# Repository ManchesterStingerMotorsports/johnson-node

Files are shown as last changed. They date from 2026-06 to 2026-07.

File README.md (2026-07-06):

# Johnson Node

The Johnson Node is a modular CAN node for sensor networks. It is designed as a small configurable board that can sit on a CAN bus, read local sensors or IO, and publish data for the rest of the network to use.

At its simplest, it is an ADC and IO node on CAN. A lot of the ESP32-S3 IO is broken out to a 14-pin multipin connector, so the same base board can be adapted for different sensor, control, and interface jobs without spinning a whole new main node each time.

The board can also interface with add-on hats. This repo currently includes hat hardware for:

- GPS and IMU
- Strain gauge interface

## Name

This project is named the "Johnson node" after Alexander Johnson, who did a dissertation on the preliminary prototype. 

In reality this project has now far exceeded the scope of the original dissertation but the name remains as a legacy artefact and a reminder of the original work it was built upon, and the iterative nature of engineering development.

> If I have seen further it is by standing on the shoulders of giants.  
> — Isaac Newton

## Repository Layout

| Path | Purpose |
| --- | --- |
| `hardware/johnson-node/` | Main Johnson Node KiCad project, schematic, and PCB. |
| `hardware/hats/IMU, GPS/` | GPS and IMU hat KiCad project. |
| `hardware/hats/Strain Gauge Interface/` | Strain gauge interface hat KiCad project. |
| `main/` | Big Scary Code Blob (jokes, i've actually tried my best to make it readable) |
| `sdkconfig` | ESP-IDF configuration for the ESP32-S3 target. |

## Hardware Overview

The base board is built around an ESP32-S3 module and CAN bus interface. Its role is to provide:

- CAN connectivity for distributed sensor networks.
- Local ADC and IO handling.
- A 14-pin multipin connector exposing a broad set of IO.
- Expansion through application-specific hats.
- A reusable base for different sensor-node configurations.

## Development Notes

- `build/` is generated by ESP-IDF and should not be edited by hand.
- `sdkconfig` is committed so target and flash settings are reproducible.
- The top-level CMake file enables `MINIMAL_BUILD`, so new ESP-IDF component dependencies should be added explicitly in `main/CMakeLists.txt`.

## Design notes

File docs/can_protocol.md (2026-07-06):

# Johnson Node CAN Protocol

The Johnson Node uses 11-bit CAN identifiers at 1 Mbit/s. All multi-byte
values are big-endian. Signed values use two's-complement representation.

This is the initial node-local allocation. It should be reconciled with the
vehicle-wide CAN database before multiple Johnson Nodes are deployed.

## ADC

| ID | Name | Payload |
| --- | --- | --- |
| `0x100` | ADC A | A, B, C, D as four unsigned 16-bit raw counts |
| `0x101` | ADC B | E, F, G, H as four unsigned 16-bit raw counts |

Raw ADC values occupy the range 0 to 4095. Voltage is calculated locally as
`raw * 5.0 / 4096`, but raw values are transmitted so the reference voltage
can be calibrated during analysis.

| Input | Device/channel | Base-board connector |
| --- | --- | --- |
| A | ADC A IN1 | J2 |
| B | ADC A IN2 | J4 |
| C | ADC A IN3 | J3 |
| D | ADC A IN4 | J5 |
| E | ADC B IN1 | J6 |
| F | ADC B IN2 | J7 |
| G | ADC B IN3 | J8 |
| H | ADC B IN4 | J9 |

## IMU

Vector frames contain X, Y, and Z as three signed 16-bit values followed by
two reserved bytes.

| ID | Name | Scale |
| --- | --- | --- |
| `0x110` | Acceleration | `0.01 m/s^2` per bit |
| `0x111` | Linear acceleration | `0.01 m/s^2` per bit |
| `0x112` | Gravity | `0.01 m/s^2` per bit |
| `0x113` | Gyroscope | `0.001 rad/s` per bit |
| `0x114` | Magnetometer | `0.1 uT` per bit |
| `0x115` | Euler orientation | Heading `u16`, roll `i16`, pitch `i16`, two reserved bytes; angles are `0.01 degree` per bit |
| `0x116` | Quaternion | W, X, Y, Z as signed Q14 values |
| `0x117` | IMU status | Packed calibration `u8`, temperature `i8`, six reserved bytes |

The calibration byte is packed as system, gyro, accelerometer, and
magnetometer, with two bits per field in that order.

## GPS

| ID | Name | Payload |
| --- | --- | --- |
| `0x120` | Position | Latitude `i32` and longitude `i32`, both in degrees times `1e7` |
| `0x121` | Motion | Altitude `i32` in centimetres, speed `u16` in centimetres per second, course `u16` in centidegrees |
| `0x122` | GPS status | Flags `u8`, satellites `u8`, HDOP times 100 `u16`, PPS count `u16`, two reserved bytes |
| `0x123` | UTC time | Year `u16`, month, day, hour, minute, second, centisecond |

GPS status flag bit 0 indicates a valid fix. Bit 1 indicates that at least one
PPS edge has been received.

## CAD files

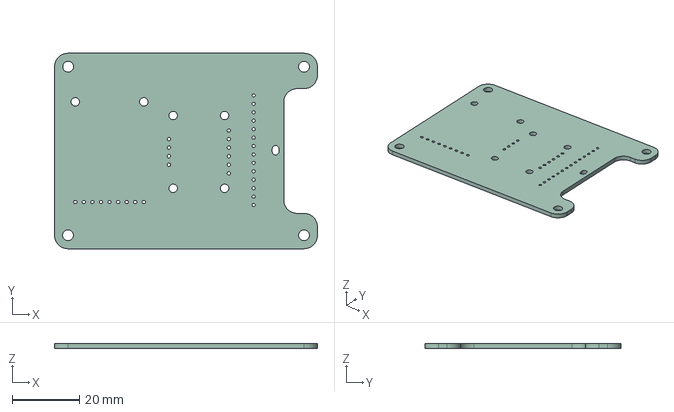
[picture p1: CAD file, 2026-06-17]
hardware/hats/IMU, GPS/.step
78.0 x 58.0 x 1.51 mm

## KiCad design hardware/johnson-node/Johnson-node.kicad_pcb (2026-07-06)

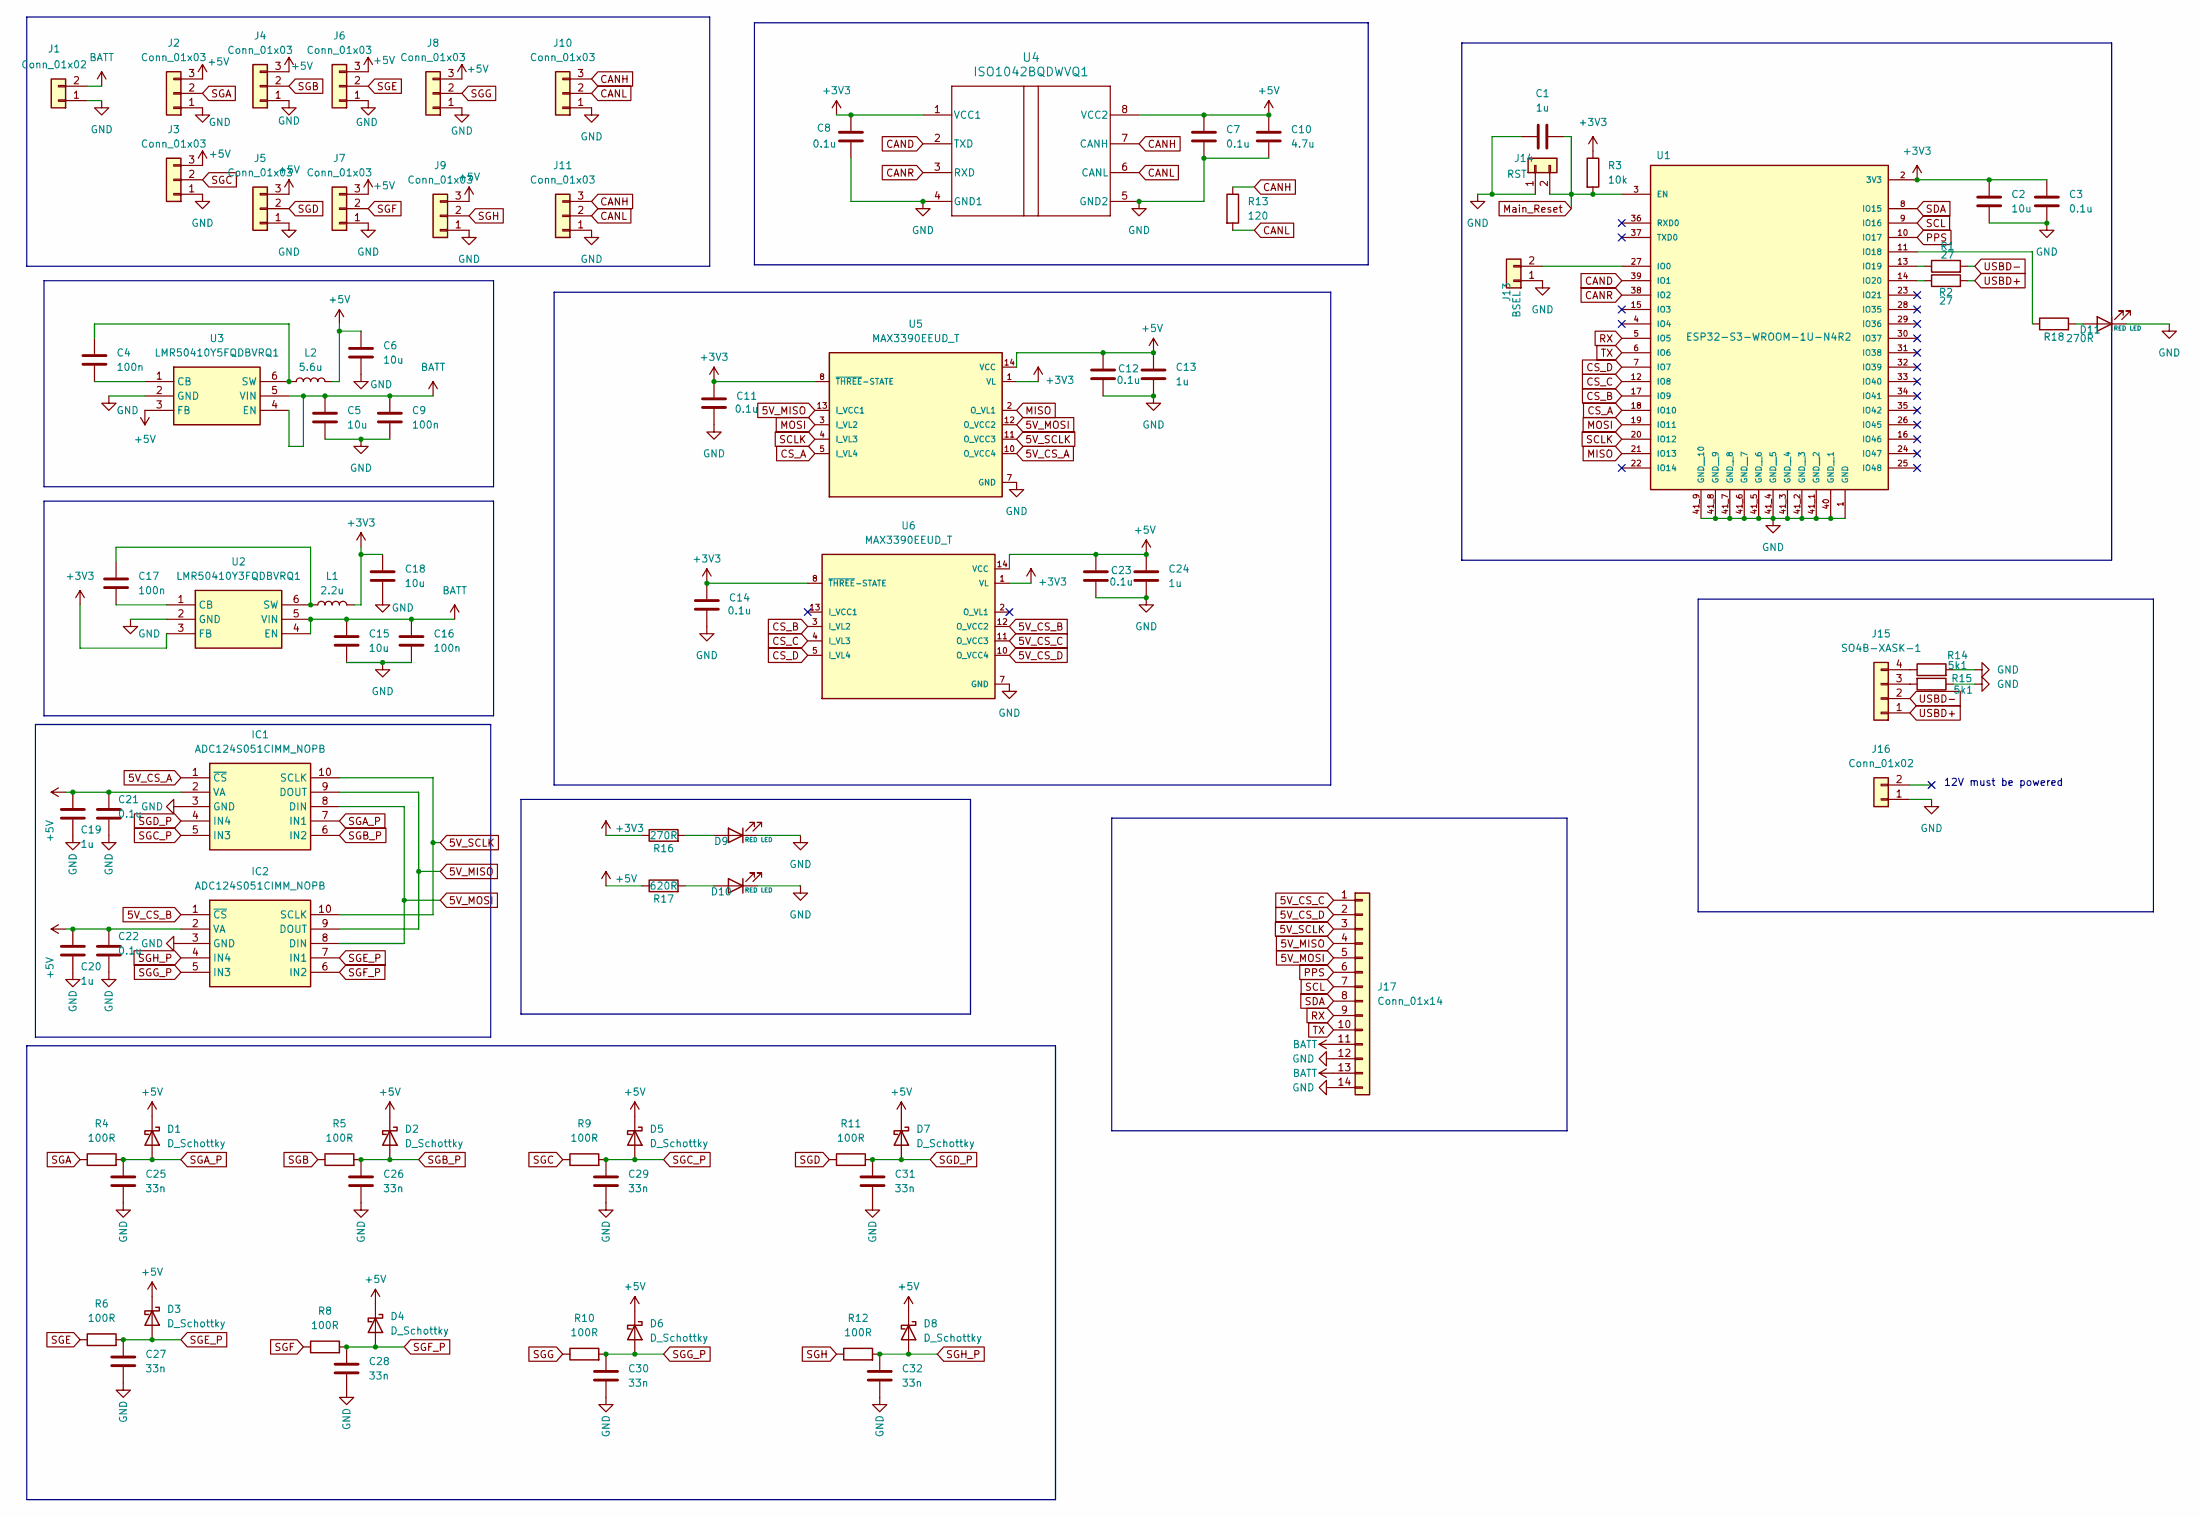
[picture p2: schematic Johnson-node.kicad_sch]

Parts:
C1, C13, C19, C20, C24: 1u; C_0603_1608Metric
C2, C5, C6, C15, C18: 10u; C_0603_1608Metric
C3, C7, C8, C11, C12, C14, C21, C22, C23: 0.1u; C_0603_1608Metric
C4, C9, C16, C17: 100n; C_0603_1608Metric
C10: 4.7u; C_0603_1608Metric
C25, C26, C27, C28, C29, C30, C31, C32: 33n; C_0603_1608Metric
D1, D2, D3, D4, D5, D6, D7, D8: D_Schottky; D_0603_1608Metric
D9, D10, D11: RED LED; LED_0603_1608Metric; Part Number AP2012EC
IC1, IC2: ADC124S051CIMM_NOPB; SOP50P490X110-10N; Mouser Part Number 926-AD124S051CIMMNPB
J1, J16: Conn_01x02; JST_XA_S02B-XASK-1_1x02_P2.50mm_Horizontal
J2, J3, J4, J5, J6, J7, J8, J9, J10, J11: Conn_01x03; JST_XA_S03B-XASK-1_1x03_P2.50mm_Horizontal
J13: BSEL; PinHeader_1x02_P2.54mm_Vertical
J14: RST; PinHeader_1x02_P2.54mm_Vertical
J15: SO4B-XASK-1; JST_XA_S04B-XASK-1_1x04_P2.50mm_Horizontal
J17: Conn_01x14; JST_XA_B14B-XASK-1_1x14_P2.50mm_Vertical
L1: 2.2u; WE-TPC_4828
L2: 5.6u; WE-TPC_4828
R1, R2: 27; R_0603_1608Metric
R3: 10k; R_0603_1608Metric
R4, R5, R6, R8, R9, R10, R11, R12: 100R; R_0603_1608Metric
R13: 120; R_0603_1608Metric
R14, R15: 5k1; R_0603_1608Metric
R16, R18: 270R; R_0603_1608Metric; Part Number RC0805FR-07270RL
R17: 620R; R_0603_1608Metric; Part Number RC0805FR-07270RL
U1: ESP32-S3-WROOM-1U-N4R2; XCVR_ESP32-S3-WROOM-1U-N4R2; PARTREV v1.1
U2: LMR50410Y3FQDBVRQ1; SOT95P280X145-6N; Mouser Part Number 595-R50410Y3FQDBVRQ1
U3: LMR50410Y5FQDBVRQ1; SOT95P280X145-6N; Mouser Part Number 595-R50410Y3FQDBVRQ1
U4: ISO1042BQDWVQ1; DWV0008A-MFG
U5, U6: MAX3390EEUD_T; SOP65P640X110-14N

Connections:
5V_CS_A: IC1.1 (~CS), U5.10 (O_VCC4)
5V_CS_B: IC2.1 (~CS), U6.12 (O_VCC2)
5V_CS_C: J17.1, U6.11 (O_VCC3)
5V_CS_D: J17.2, U6.10 (O_VCC4)
5V_MISO: IC1.9 (DOUT), IC2.9 (DOUT), J17.4, U5.13 (I_VCC1)
5V_MOSI: IC1.8 (DIN), IC2.8 (DIN), J17.5, U5.12 (O_VCC2)
5V_SCLK: IC1.10 (SCLK), IC2.10 (SCLK), J17.3, U5.11 (O_VCC3)
+3V3: C2.2, C3.2, C8.2, C11.1, C14.1, C18.1, L1.2, R3.1, R16.1, U1.2 (3V3), U2.3 (FB), U4.1 (VCC1), U5.1 (VL), U5.8 (~THREE-STATE), U6.1 (VL), U6.8 (~THREE-STATE)
+5V: C6.1, C7.2, C10.2, C12.1, C13.1, C19.1, C20.1, C21.1, C22.1, C23.1, C24.1, D1.1 (K), D2.1 (K), D3.1 (K), D4.1 (K), D5.1 (K), D6.1 (K), D7.1 (K), D8.1 (K), IC1.2 (VA), IC2.2 (VA), J2.3, J3.3, J4.3, J5.3, J6.3, J7.3, J8.3, J9.3, L2.2, R17.1, U3.3 (FB), U4.8 (VCC2), U5.14 (VCC), U6.14 (VCC)
BATT: C5.1, C9.1, C15.1, C16.1, J1.2, J17.11, J17.13, U2.4 (EN), U2.5 (VIN), U3.4 (EN), U3.5 (VIN)
CAND: U1.39 (IO1), U4.2 (TXD)
CANH: J10.3, J11.3, R13.1, U4.7 (CANH)
CANL: J10.2, J11.2, R13.2, U4.6 (CANL)
CANR: U1.38 (IO2), U4.3 (RXD)
CS_A: U1.18 (IO10), U5.5 (I_VL4)
CS_B: U1.17 (IO9), U6.3 (I_VL2)
CS_C: U1.12 (IO8), U6.4 (I_VL3)
CS_D: U1.7 (IO7), U6.5 (I_VL4)
GND: C1.1, C2.1, C3.1, C5.2, C6.2, C7.1, C8.1, C9.2, C10.1, C11.2, C12.2, C13.2, C14.2, C15.2, C16.2, C18.2, C19.2, C20.2, C21.2, C22.2, C23.2, C24.2, C25.2, C26.2, C27.2, C28.2, C29.2, C30.2, C31.2, C32.2, D9.1 (K), D10.1 (K), D11.1 (K), IC1.3 (GND), IC2.3 (GND), J1.1, J2.1, J3.1, J4.1, J5.1, J6.1, J7.1, J8.1, J9.1, J10.1, J11.1, J13.1, J14.1, J16.1 (Pin_1_1), J17.12, J17.14, R14.2, R15.1, U1.1 (GND), U1.40 (GND__1), U1.41_1 (GND__2), U1.41_2 (GND__3), U1.41_3 (GND__4), U1.41_4 (GND__5), U1.41_5 (GND__6), U1.41_6 (GND__7), U1.41_7 (GND__8), U1.41_8 (GND__9), U1.41_9 (GND__10), U2.2 (GND), U3.2 (GND), U4.4 (GND1), U4.5 (GND2), U5.7 (GND), U6.7 (GND); also elsewhere on the board
MISO: U1.21 (IO13), U5.2 (O_VL1)
MOSI: U1.19 (IO11), U5.3 (I_VL2)
Main_Reset: C1.2, J14.2, R3.2, U1.3 (EN)
unnamed 22: D9.2 (A), R16.2; also elsewhere on the board
unnamed 23: D10.2 (A), R17.2; also elsewhere on the board
unnamed 24: D11.2 (A), R18.2; also elsewhere on the board
unnamed: J13.2, U1.27 (IO0)
unnamed: J15.3, R15.2
unnamed: J15.4, R14.1
unnamed: R18.1, U1.11 (IO18)
unnamed: R1.1, U1.13 (IO19)
unnamed: R2.1, U1.14 (IO20)
unnamed: C17.2, U2.1 (CB)
unnamed: C17.1, L1.1, U2.6 (SW)
unnamed: C4.2, U3.1 (CB)
unnamed: C4.1, L2.1, U3.6 (SW)
PPS: J17.6, U1.10 (IO17)
RX: J17.9, U1.5 (IO5)
SCL: J17.7, U1.9 (IO16)
SCLK: U1.20 (IO12), U5.4 (I_VL3)
SDA: J17.8, U1.8 (IO15)
SGA: J2.2, R4.1
SGA_P: C25.1, D1.2 (A), IC1.7 (IN1), R4.2
SGB: J4.2, R5.1
SGB_P: C26.1, D2.2 (A), IC1.6 (IN2), R5.2
SGC: J3.2, R9.1
SGC_P: C29.1, D5.2 (A), IC1.5 (IN3), R9.2
SGD: J5.2, R11.1
SGD_P: C31.1, D7.2 (A), IC1.4 (IN4), R11.2
SGE: J6.2, R6.1
SGE_P: C27.1, D3.2 (A), IC2.7 (IN1), R6.2
SGF: J7.2, R8.1
SGF_P: C28.1, D4.2 (A), IC2.6 (IN2), R8.2
SGG: J8.2, R10.1
SGG_P: C30.1, D6.2 (A), IC2.5 (IN3), R10.2
SGH: J9.2, R12.1
SGH_P: C32.1, D8.2 (A), IC2.4 (IN4), R12.2
TX: J17.10, U1.6 (IO6)
USBD+: J15.1, R2.2
USBD-: J15.2, R1.2

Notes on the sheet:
12V must be powered

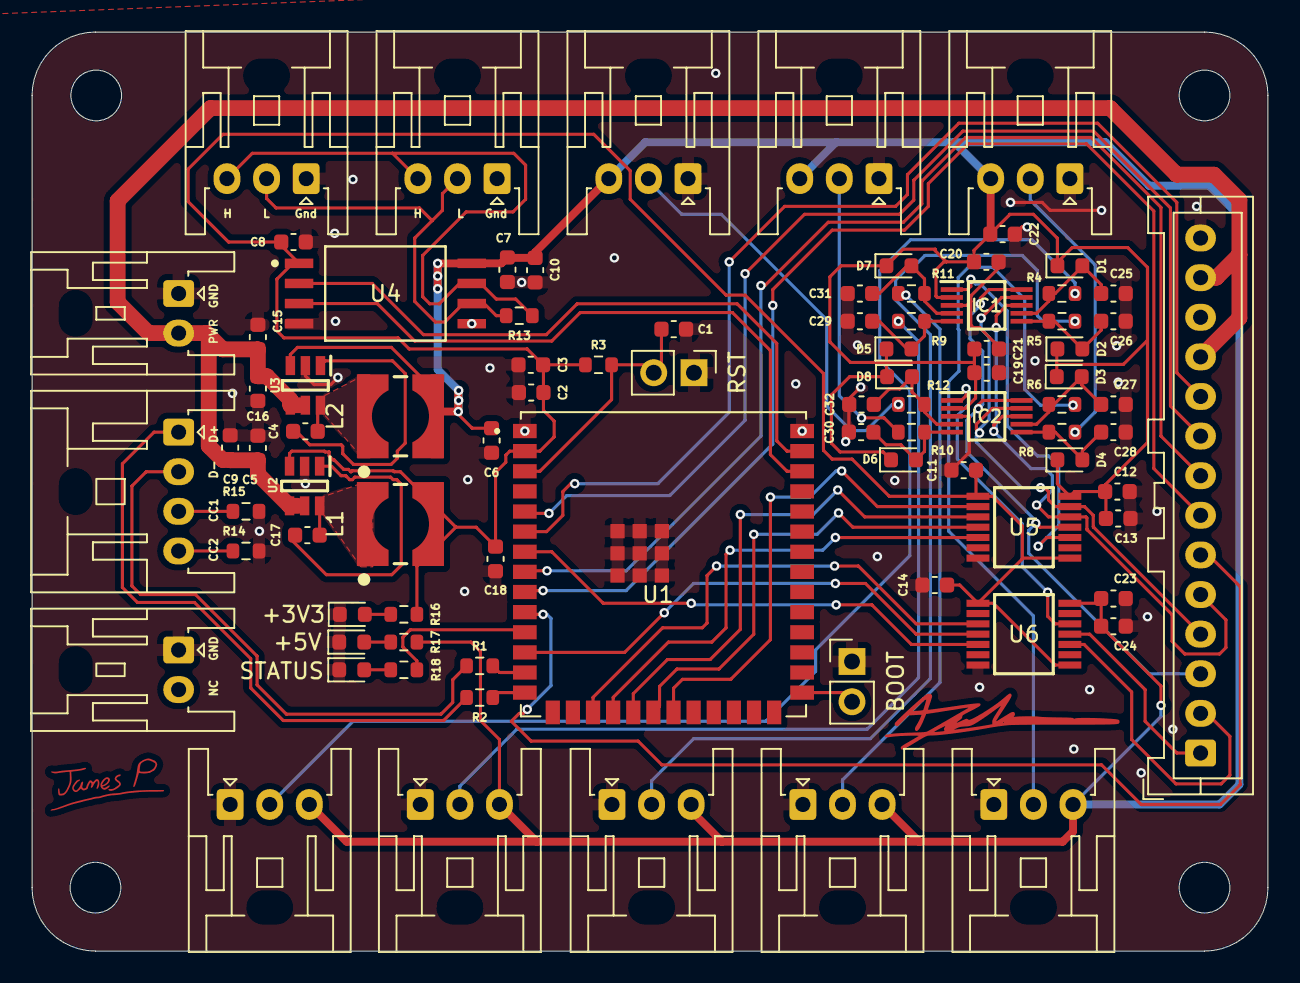
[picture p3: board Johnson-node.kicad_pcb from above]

Board: 2 copper layers, 78.0 x 58.0 mm, 86 parts (0 on the bottom side), 59 nets.

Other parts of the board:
+3V3, +5V: RED LED; LED_0603_1608Metric
STATUS: RED LED; LED_0603_1608Metric

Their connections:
GND: +3V3.1 (K), +5V.1 (K), STATUS.1 (K); also elsewhere on the board
unnamed 22: +3V3.2 (A); also elsewhere on the board
unnamed 23: +5V.2 (A); also elsewhere on the board
unnamed 24: STATUS.2 (A); also elsewhere on the board

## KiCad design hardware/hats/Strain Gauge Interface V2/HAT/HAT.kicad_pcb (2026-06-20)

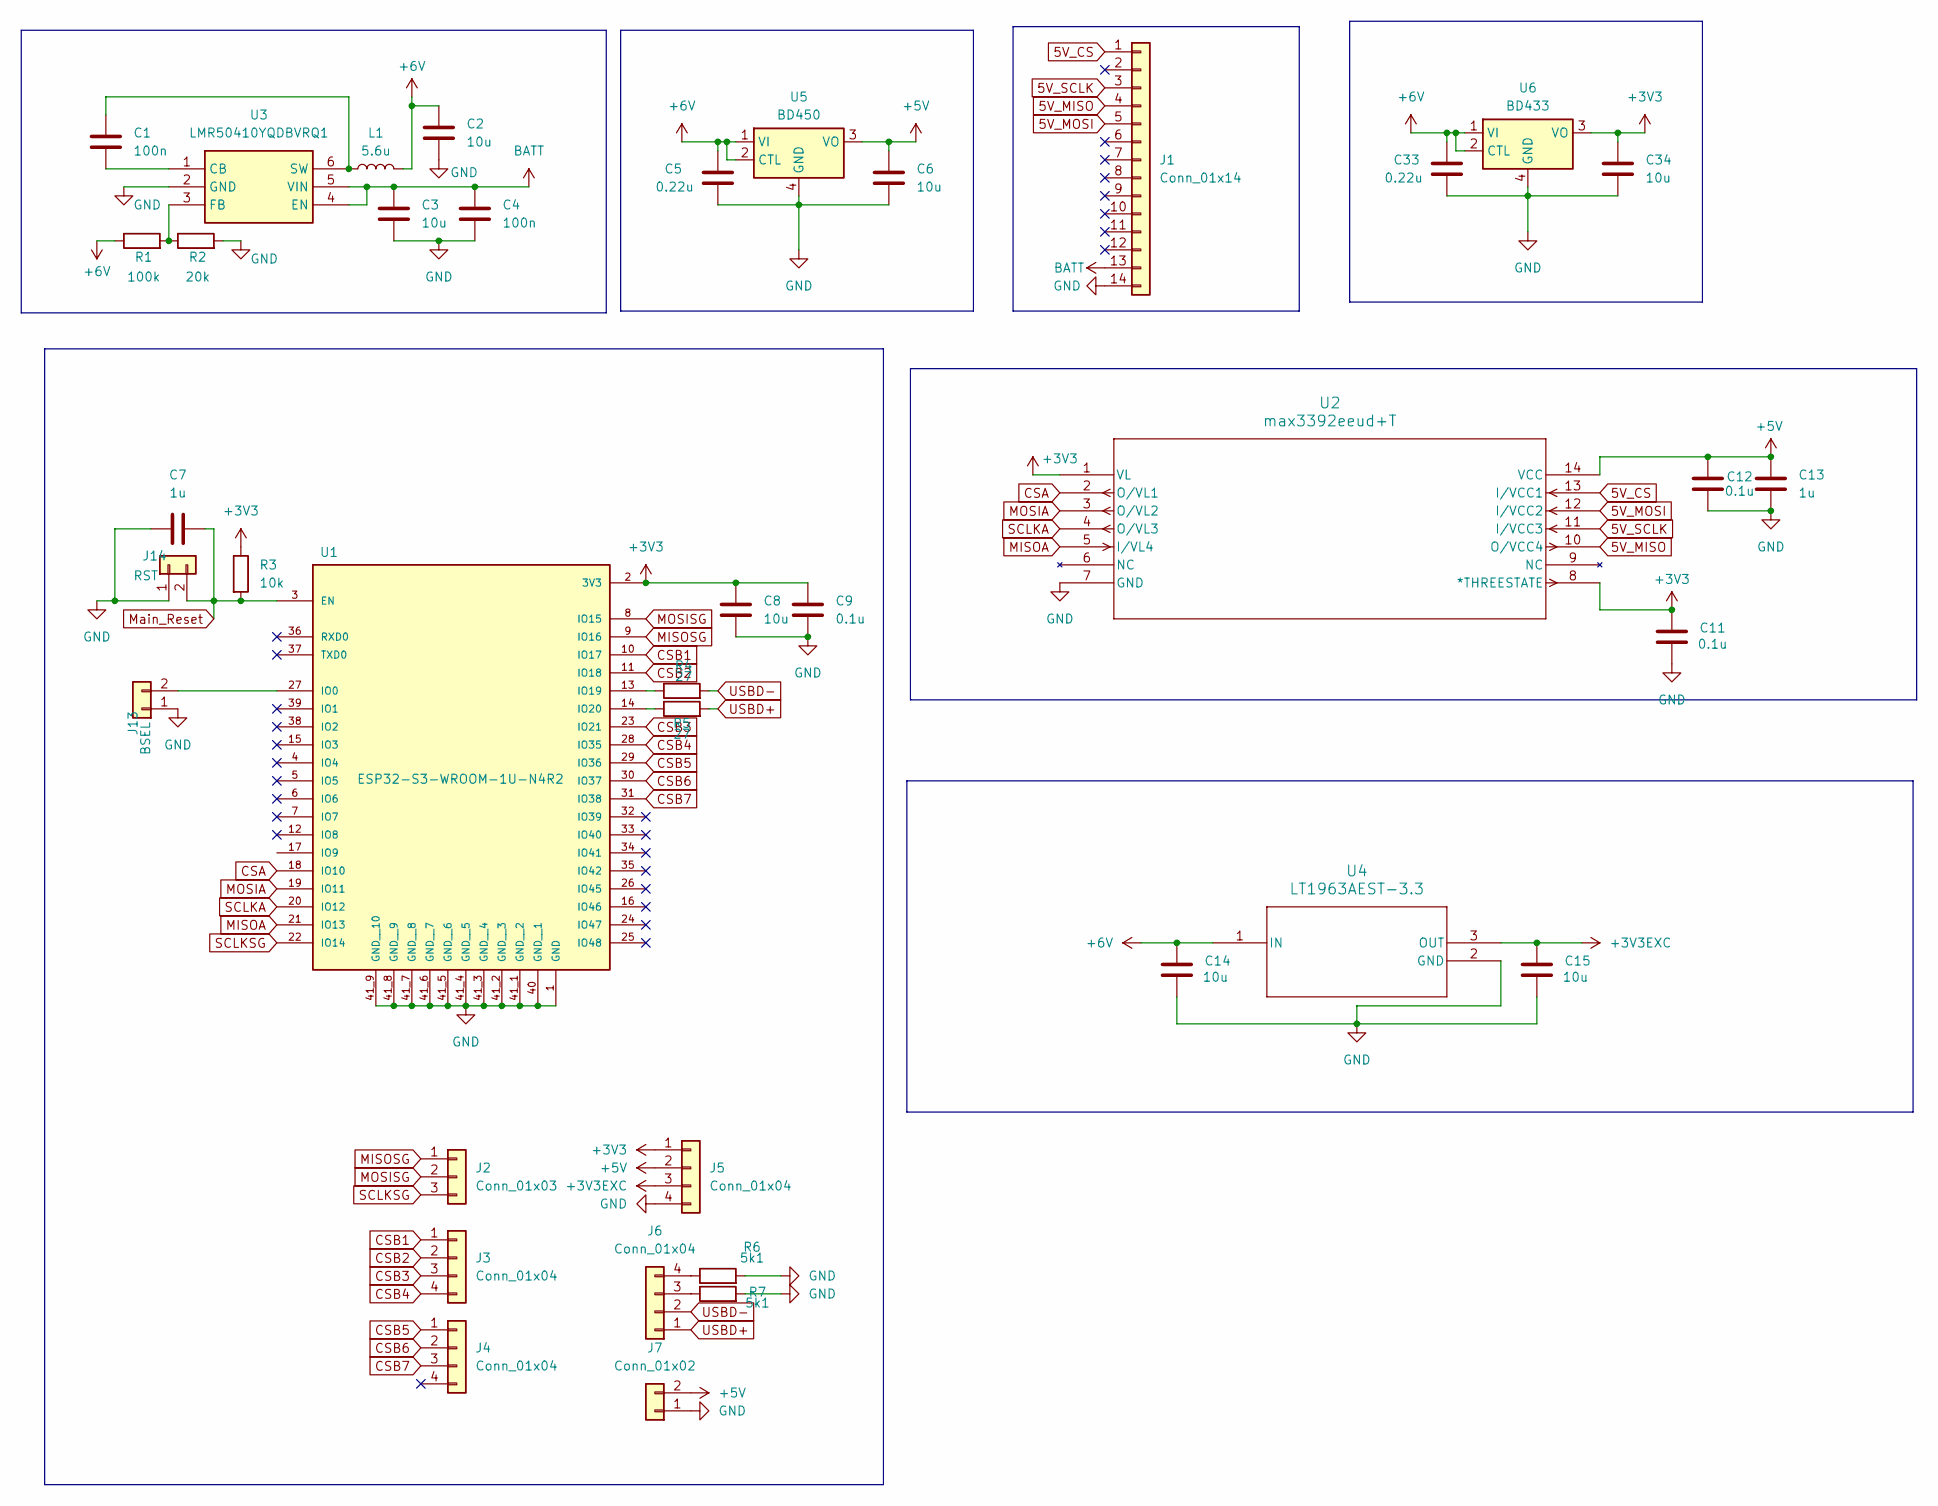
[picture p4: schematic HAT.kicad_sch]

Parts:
C1, C4: 100n; C_0603_1608Metric
C2, C3, C6, C8, C14, C15, C34: 10u; C_0603_1608Metric
C5, C33: 0.22u; C_0603_1608Metric
C7, C13: 1u; C_0603_1608Metric
C9, C11, C12: 0.1u; C_0603_1608Metric
J1: Conn_01x14; JST_XA_S14B-XASK-1_1x14_P2.50mm_Horizontal
J2: Conn_01x03; JST_XA_S03B-XASK-1_1x03_P2.50mm_Horizontal
J3, J4, J5, J6: Conn_01x04; JST_XA_S04B-XASK-1_1x04_P2.50mm_Horizontal
J7: Conn_01x02; JST_XA_S02B-XASK-1_1x02_P2.50mm_Horizontal
J13: BSEL; PinHeader_1x02_P2.54mm_Vertical
J14: RST; PinHeader_1x02_P2.54mm_Vertical
L1: 5.6u; WE-TPC_4828
R1: 100k; R_0603_1608Metric
R2: 20k; R_0603_1608Metric
R3: 10k; R_0603_1608Metric
R4, R5: 27; R_0603_1608Metric
R6, R7: 5k1; R_0603_1608Metric
U1: ESP32-S3-WROOM-1U-N4R2; XCVR_ESP32-S3-WROOM-1U-N16R8; PARTREV v1.1
U2: max3392eeud+T; 21-0066J_14_MXM
U3: LMR50410YQDBVRQ1; Regulator_Switching_SOT-23-6; Mouser Part Number 595-R50410Y3FQDBVRQ1
U4: LT1963AEST-3.3; SOT-223-3_TabPin2
U5: BD450; Regulator_Linear_SOT-223-4
U6: BD433; Regulator_Linear_SOT-223-4

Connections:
5V_CS: J1.1, U2.13 (I/VCC1)
5V_MISO: J1.4, U2.10 (O/VCC4)
5V_MOSI: J1.5, U2.12 (I/VCC2)
5V_SCLK: J1.3, U2.11 (I/VCC3)
+3V3: C8.2, C9.2, C11.1, C34.1, J5.1, R3.1, U1.2 (3V3), U2.1 (VL), U2.8 (*THREESTATE), U6.3 (VO)
+3V3EXC: C15.1, J5.3, U4.3 (OUT)
+5V: C6.1, C12.1, C13.1, J5.2, J7.2, U2.14 (VCC), U5.3 (VO)
+6V: C2.1, C5.1, C14.1, C33.1, L1.2, R1.1, U4.1 (IN), U5.1 (VI), U5.2 (CTL), U6.1 (VI), U6.2 (CTL)
BATT: C3.1, C4.1, J1.13, U3.4 (EN), U3.5 (VIN)
CSA: U1.18 (IO10), U2.2 (O/VL1)
CSB1: J3.1, U1.10 (IO17)
CSB2: J3.2, U1.11 (IO18)
CSB3: J3.3, U1.23 (IO21)
CSB4: J3.4, U1.28 (IO35)
CSB5: J4.1, U1.29 (IO36)
CSB6: J4.2, U1.30 (IO37)
CSB7: J4.3, U1.31 (IO38)
GND: C2.2, C3.2, C4.2, C5.2, C6.2, C7.1, C8.1, C9.1, C11.2, C12.2, C13.2, C14.2, C15.2, C33.2, C34.2, J1.14, J5.4, J7.1, J13.1, J14.1, R2.2, R6.2, R7.2, U1.1 (GND), U1.40 (GND__1), U1.41_1 (GND__2), U1.41_2 (GND__3), U1.41_3 (GND__4), U1.41_4 (GND__5), U1.41_5 (GND__6), U1.41_6 (GND__7), U1.41_7 (GND__8), U1.41_8 (GND__9), U1.41_9 (GND__10), U2.7 (GND), U3.2 (GND), U4.2 (GND), U5.4 (GND), U6.4 (GND)
MISOA: U1.21 (IO13), U2.5 (I/VL4)
MISOSG: J2.1, U1.9 (IO16)
MOSIA: U1.19 (IO11), U2.3 (O/VL2)
MOSISG: J2.2, U1.8 (IO15)
Main_Reset: C7.2, J14.2, R3.2, U1.3 (EN)
unnamed: J6.3, R7.1
unnamed: J6.4, R6.1
unnamed: J13.2, U1.27 (IO0)
unnamed: R4.1, U1.13 (IO19)
unnamed: R5.1, U1.14 (IO20)
unnamed: C1.2, U3.1 (CB)
unnamed: R1.2, R2.1, U3.3 (FB)
unnamed: C1.1, L1.1, U3.6 (SW)
SCLKA: U1.20 (IO12), U2.4 (O/VL3)
SCLKSG: J2.3, U1.22 (IO14)
USBD+: J6.1, R5.2
USBD-: J6.2, R4.2

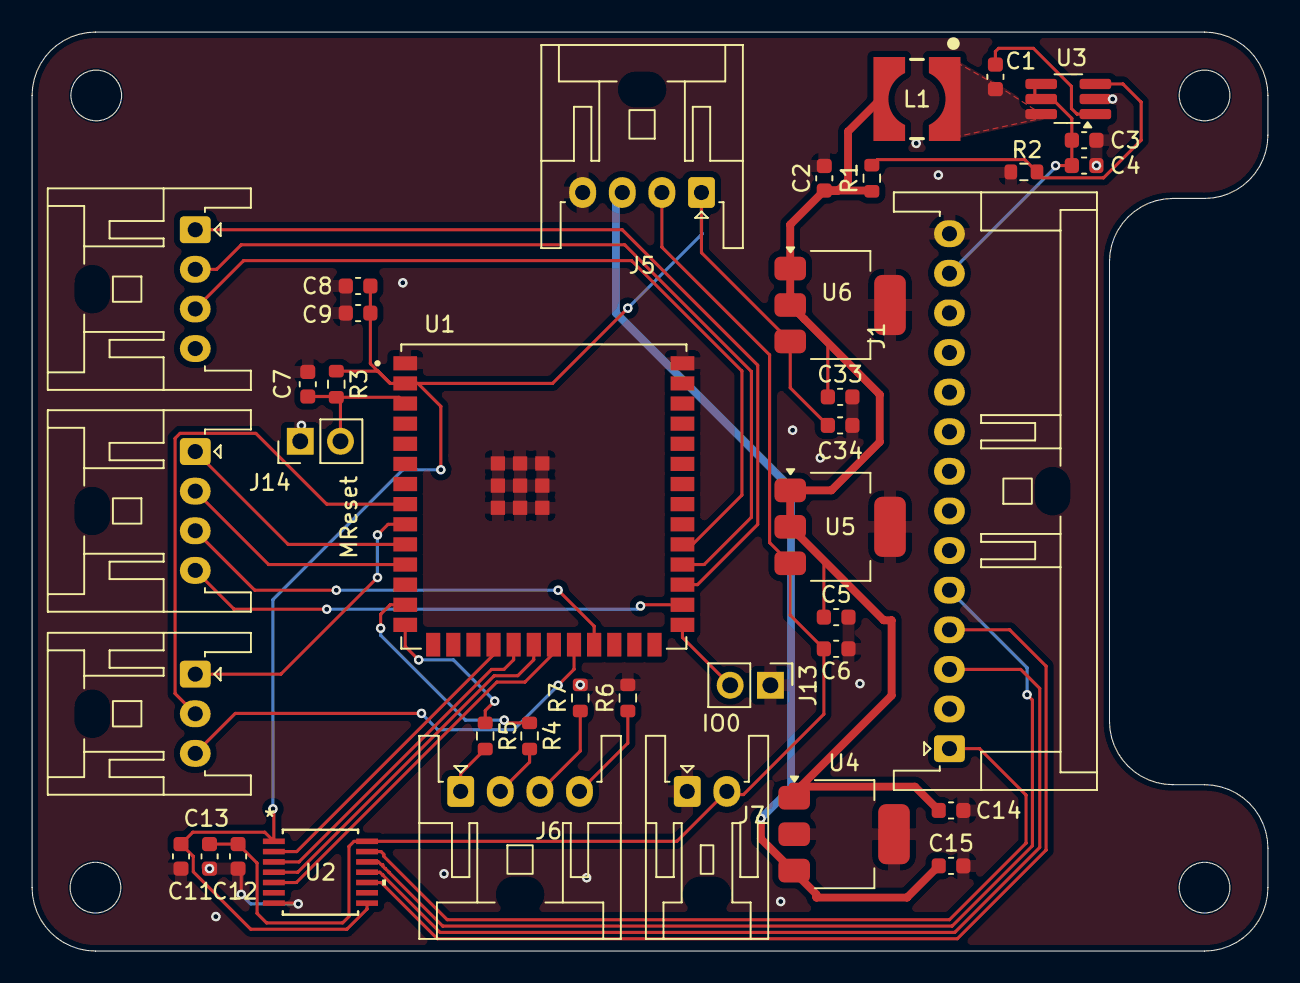
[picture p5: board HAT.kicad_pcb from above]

Board: 2 copper layers, 78.0 x 58.0 mm, 39 parts (0 on the bottom side), 35 nets.

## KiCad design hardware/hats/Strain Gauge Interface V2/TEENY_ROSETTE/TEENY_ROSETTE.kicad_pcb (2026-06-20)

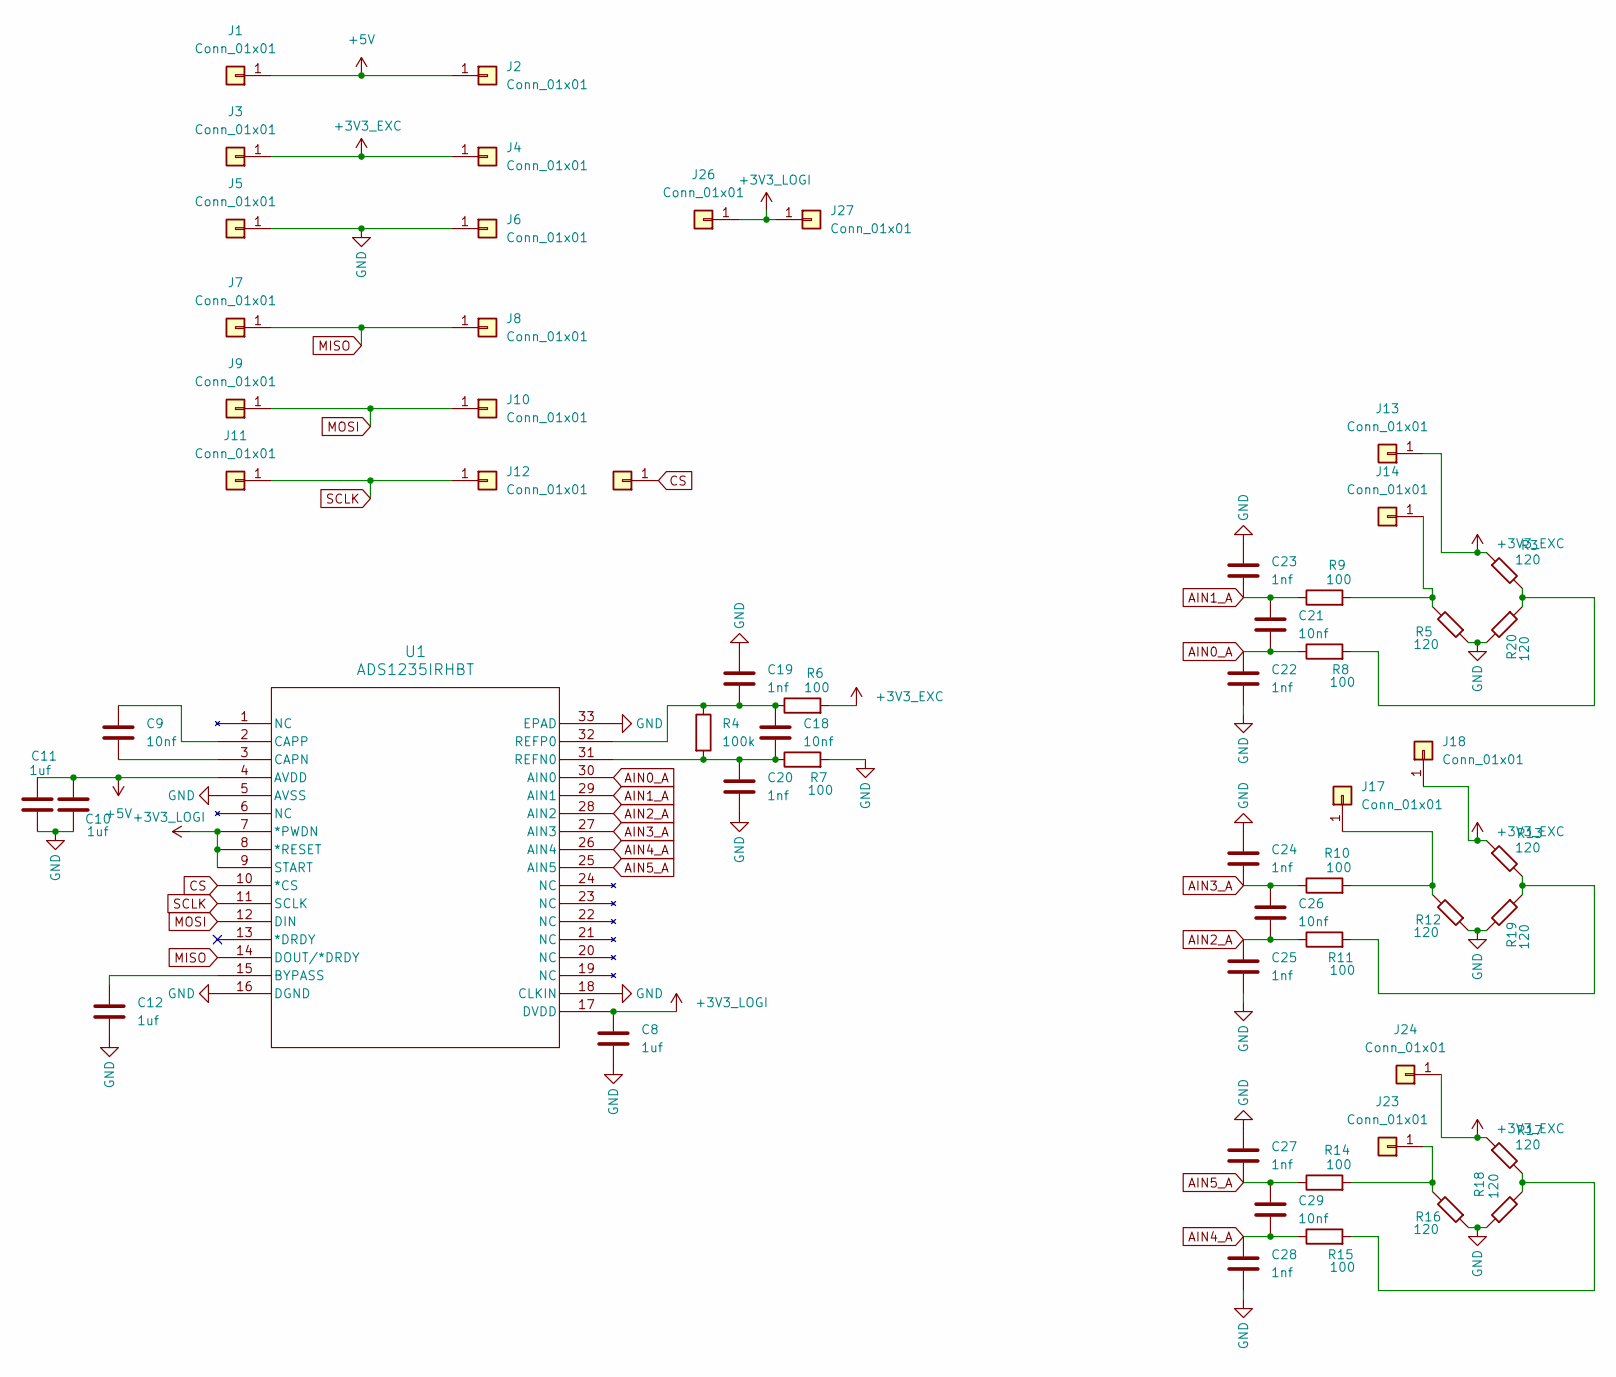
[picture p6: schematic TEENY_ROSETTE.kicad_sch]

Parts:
C8, C10, C11, C12: 1uf; C_0603_1608Metric
C9, C18, C21, C26, C29: 10nf; C_0603_1608Metric
C19, C20, C22, C23, C24, C25, C27, C28: 1nf; C_0603_1608Metric
J1, J2, J3, J4, J5, J6, J7, J8, J9, J10, J11, J12, J13, J14, J17, J18, J23, J24, J25, J26, J27: Conn_01x01; PAD
R3, R5, R12, R13, R16, R17, R18, R19, R20: 120; R_0603_1608Metric
R4: 100k; R_0603_1608Metric
R6, R7, R8, R9, R10, R11, R14, R15: 100; R_0603_1608Metric
U1: ADS1235IRHBT; RHB32_TEX

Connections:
+3V3_EXC: J3.1 (Pin_1_1), J4.1 (Pin_1_1), J13.1 (Pin_1_1), J18.1 (Pin_1_1), J24.1 (Pin_1_1), R3.1, R6.2, R13.1, R17.1
+3V3_LOGI: C8.1, J26.1 (Pin_1_1), J27.1 (Pin_1_1), U1.7 (*PWDN), U1.8 (*RESET), U1.9 (START), U1.17 (DVDD)
+5V: C10.1, C11.1, J1.1 (Pin_1_1), J2.1 (Pin_1_1), U1.4 (AVDD)
AIN0_A: C21.2, C22.1, R8.1, U1.30 (AIN0)
AIN1_A: C21.1, C23.2, R9.1, U1.29 (AIN1)
AIN2_A: C25.1, C26.2, R11.1, U1.28 (AIN2)
AIN3_A: C24.2, C26.1, R10.1, U1.27 (AIN3)
AIN4_A: C28.1, C29.2, R15.1, U1.26 (AIN4)
AIN5_A: C27.2, C29.1, R14.1, U1.25 (AIN5)
CS: J25.1 (Pin_1_1), U1.10 (*CS)
GND: C8.2, C10.2, C11.2, C12.2, C19.1, C20.2, C22.2, C23.1, C24.1, C25.2, C27.1, C28.2, J5.1 (Pin_1_1), J6.1 (Pin_1_1), R5.1, R7.2, R12.1, R16.1, R18.1, R19.2, R20.2, U1.5 (AVSS), U1.16 (DGND), U1.18 (CLKIN), U1.33 (EPAD)
MISO: J7.1 (Pin_1_1), J8.1 (Pin_1_1), U1.14 (DOUT/*DRDY)
MOSI: J9.1 (Pin_1_1), J10.1 (Pin_1_1), U1.12 (DIN)
unnamed: J14.1 (Pin_1_1), R5.2, R9.2
unnamed: J17.1 (Pin_1_1), R10.2, R12.2
unnamed: J23.1 (Pin_1_1), R14.2, R16.2
unnamed: R11.2, R13.2, R19.1
unnamed: R15.2, R17.2, R18.2
unnamed: R3.2, R8.2, R20.1
unnamed: C12.1, U1.15 (BYPASS)
unnamed: C9.2, U1.3 (CAPN)
unnamed: C9.1, U1.2 (CAPP)
unnamed: C18.2, C20.1, R4.2, R7.1, U1.31 (REFN0)
unnamed: C18.1, C19.2, R4.1, R6.1, U1.32 (REFP0)
SCLK: J11.1 (Pin_1_1), J12.1 (Pin_1_1), U1.11 (SCLK)

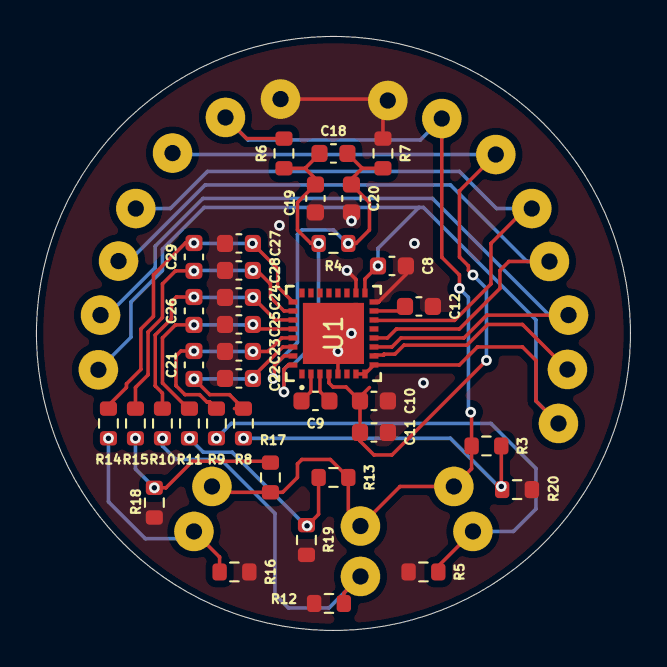
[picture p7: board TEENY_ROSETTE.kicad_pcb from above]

Board: 2 copper layers, 33.0 x 33.0 mm, 57 parts (0 on the bottom side), 25 nets.

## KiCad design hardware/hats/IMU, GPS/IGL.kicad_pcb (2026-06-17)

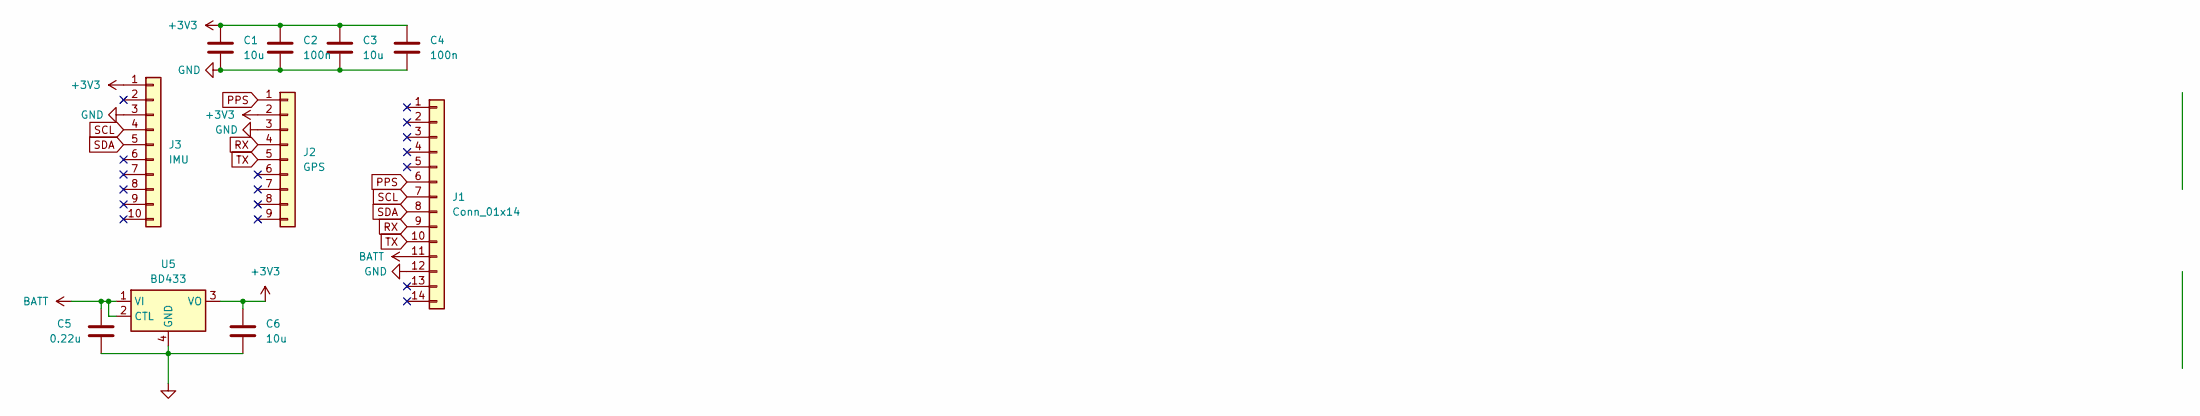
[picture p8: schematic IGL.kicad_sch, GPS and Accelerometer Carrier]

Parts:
C1, C3, C6: 10u; C_0603_1608Metric
C2, C4: 100n; C_0603_1608Metric
C5: 0.22u; C_0603_1608Metric
J1: Conn_01x14; JST_XA_S14B-XASK-1_1x14_P2.50mm_Horizontal
J2: GPS
J3: IMU
U5: BD433; Regulator_Linear_SOT-223-4

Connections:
+3V3: C1.1, C2.1, C3.1, C4.1, C6.1, J2.2, J3.1, U5.3 (VO)
BATT: C5.1, J1.11, U5.1 (VI), U5.2 (CTL)
GND: C1.2, C2.2, C3.2, C4.2, C5.2, C6.2, J1.12, J2.3, J3.3, U5.4 (GND)
PPS: J1.6, J2.1
RX: J1.9, J2.4
SCL: J1.7, J3.4
SDA: J1.8, J3.5
TX: J1.10, J2.5

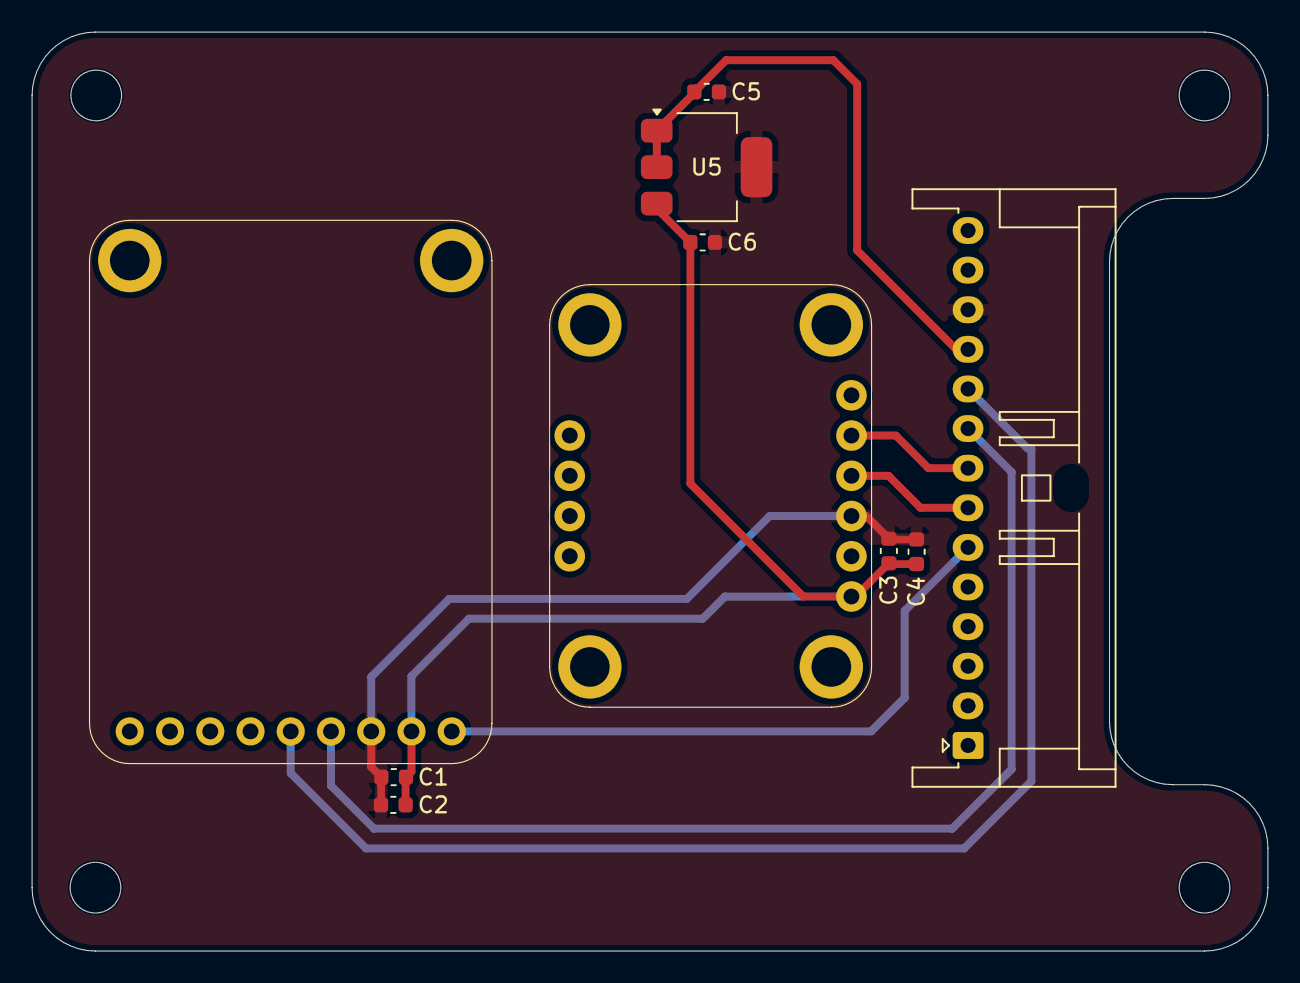
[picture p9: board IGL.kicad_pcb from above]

Board: 2 copper layers, 78.0 x 58.0 mm, 10 parts (0 on the bottom side), 8 nets.

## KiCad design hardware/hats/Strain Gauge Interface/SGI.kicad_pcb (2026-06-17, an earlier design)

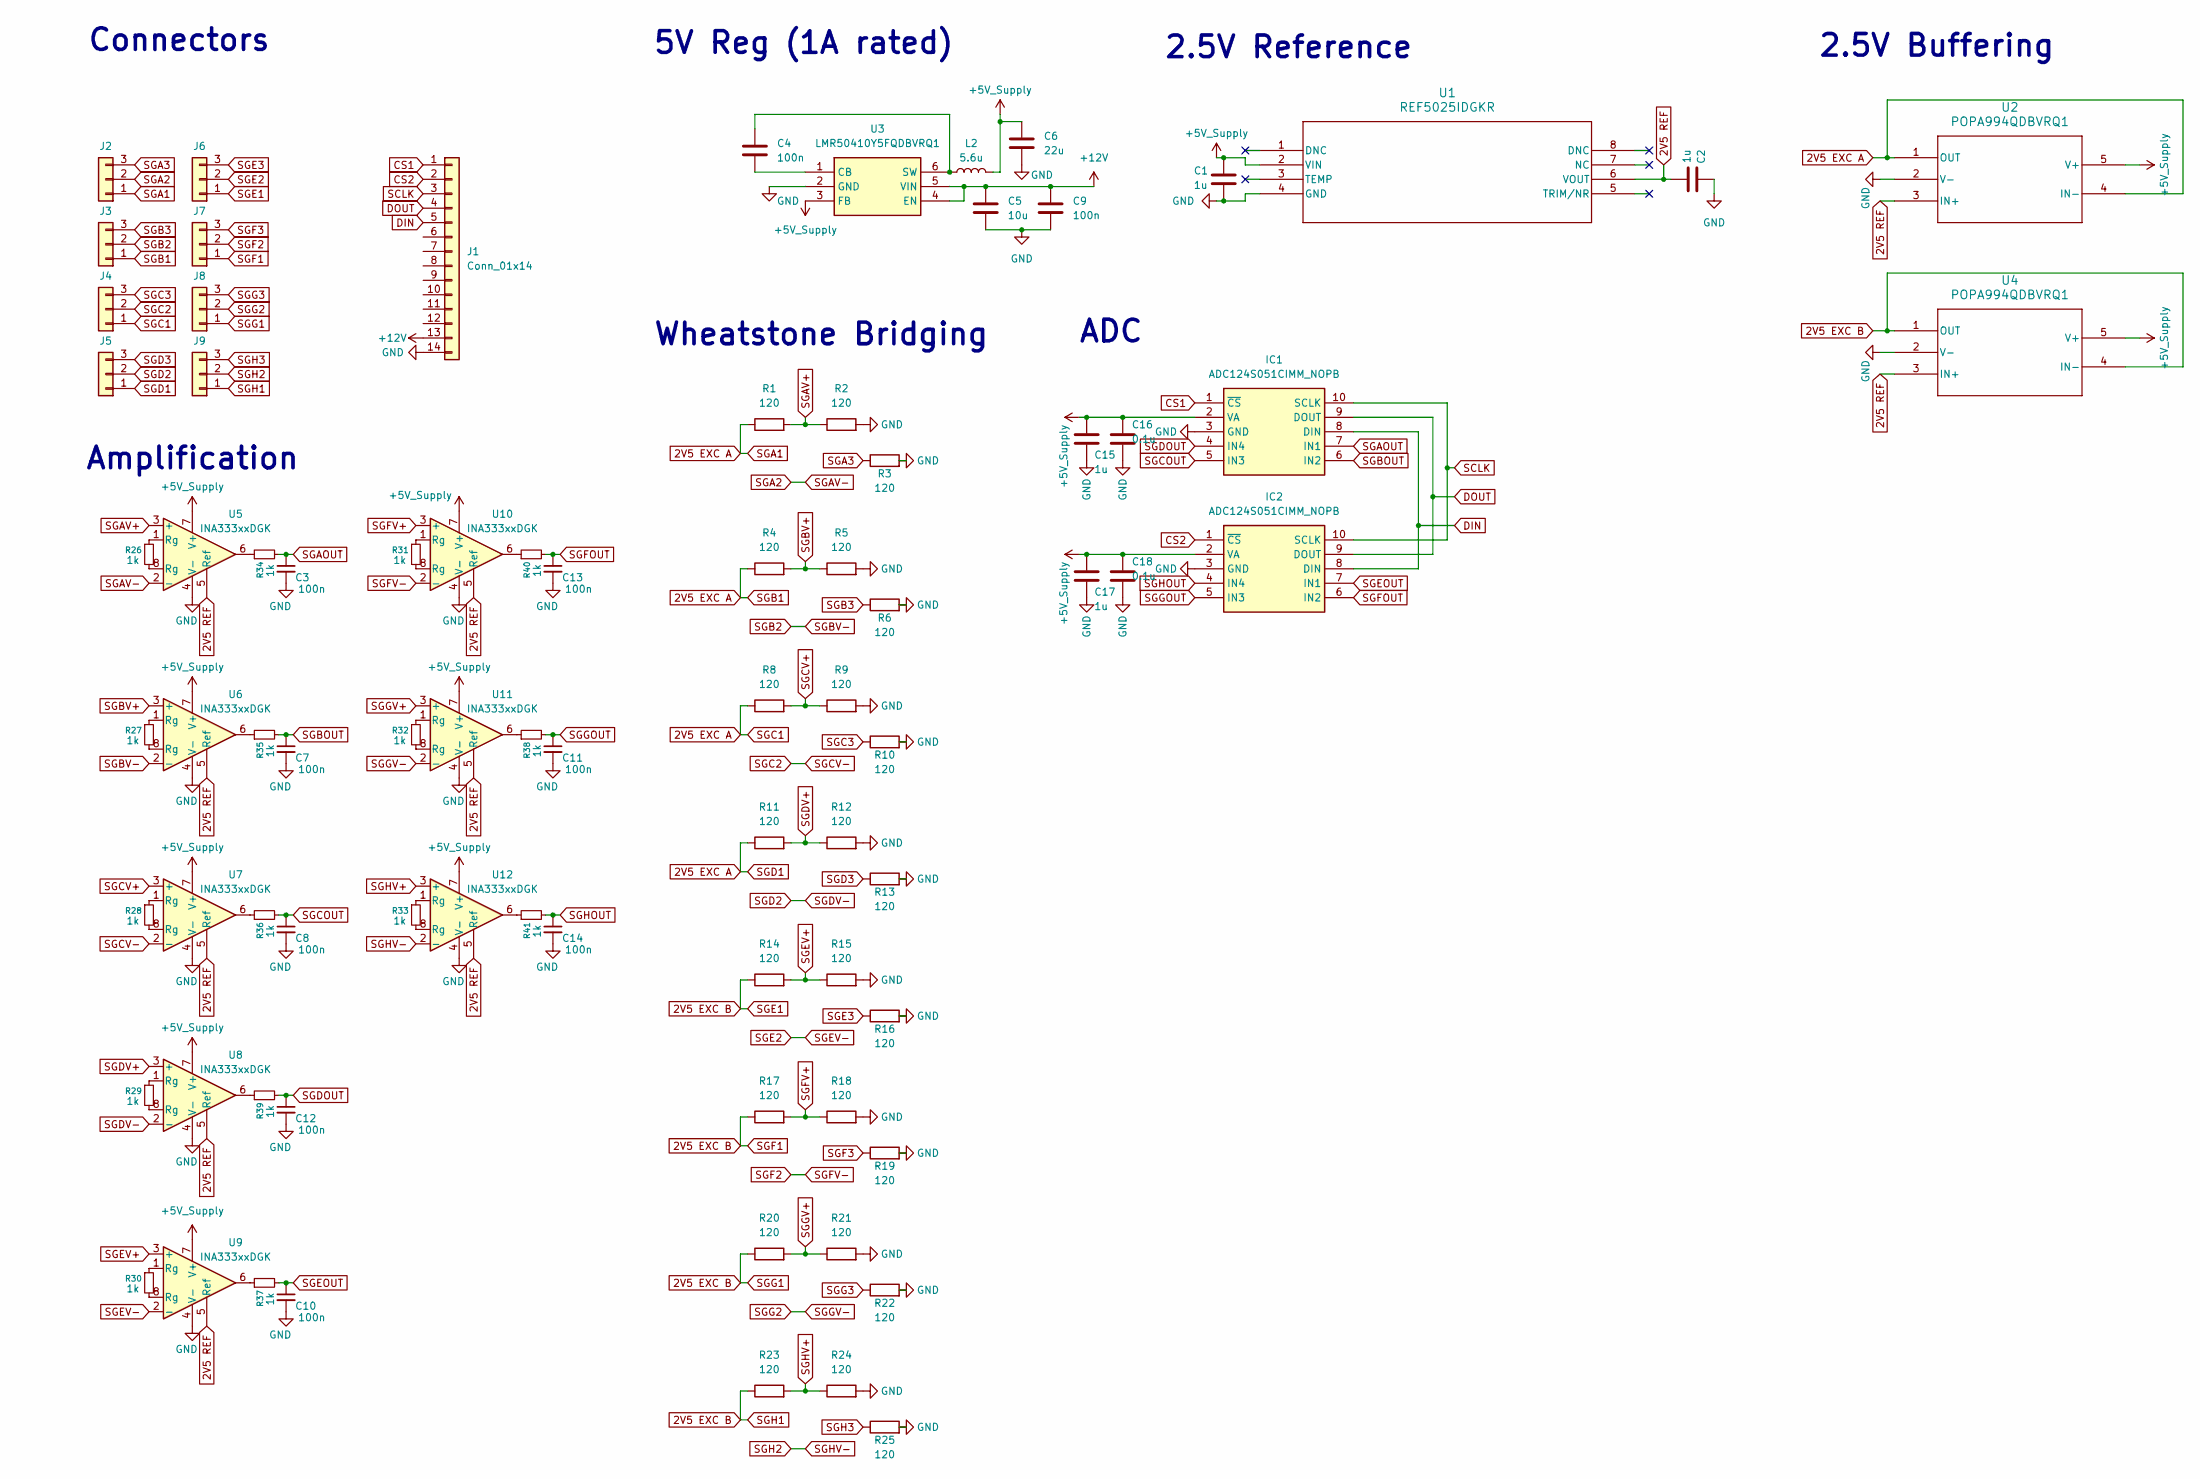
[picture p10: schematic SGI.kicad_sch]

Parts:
C1, C2, C15, C17: 1u; C_0603_1608Metric
C3, C4, C7, C8, C9, C10, C11, C12, C13, C14: 100n; C_0603_1608Metric
C5: 10u; C_0603_1608Metric
C6: 22u; C_0603_1608Metric
C16, C18: 0.1u; C_0603_1608Metric
IC1, IC2: ADC124S051CIMM_NOPB; SOP50P490X110-10N; Mouser Part Number 926-AD124S051CIMMNPB
J1: Conn_01x14; JST_XA_S14B-XASK-1_1x14_P2.50mm_Horizontal
J2, J3, J4, J5, J6, J7, J8, J9: S03B-XASK-1; JST_XA_S03B-XASK-1_1x03_P2.50mm_Horizontal
L2: 5.6u; WE-TPC_4828
R1, R2, R3, R4, R5, R6, R8, R9, R10, R11, R12, R13, R14, R15, R16, R17, R18, R19, R20, R21, R22, R23, R24, R25: 120; R_0603_1608Metric
R26, R27, R28, R29, R30, R31, R32, R33, R34, R35, R36, R37, R38, R39, R40, R41: 1k; R_0603_1608Metric
U1: REF5025IDGKR; DGK8
U2, U4: POPA994QDBVRQ1; DBV0005A_TEX
U3: LMR50410Y5FQDBVRQ1; Regulator_Switching_SOT-23-6; Mouser Part Number 595-R50410Y3FQDBVRQ1
U5, U6, U7, U8, U9, U10, U11, U12: INA333xxDGK; VSSOP-8_3x3mm_P0.65mm

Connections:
2V5 EXC A: J2.1, J3.1, J4.1, J5.1, R1.1, R4.1, R8.1, R11.1, U2.1 (OUT), U2.4 (IN-)
2V5 EXC B: J6.1, J7.1, J8.1, J9.1, R14.1, R17.1, R20.1, R23.1, U4.1 (OUT), U4.4 (IN-)
2V5 REF: C2.1, U1.6 (VOUT), U2.3 (IN+), U4.3 (IN+), U5.5 (Ref), U6.5 (Ref), U7.5 (Ref), U8.5 (Ref), U9.5 (Ref), U10.5 (Ref), U11.5 (Ref), U12.5 (Ref)
+5V_Supply: C1.2, C6.1, C15.1, C16.1, C17.1, C18.1, IC1.2 (VA), IC2.2 (VA), L2.2, U1.2 (VIN), U2.5 (V+), U3.3 (FB), U4.5 (V+), U5.7 (V+), U6.7 (V+), U7.7 (V+), U8.7 (V+), U9.7 (V+), U10.7 (V+), U11.7 (V+), U12.7 (V+)
+12V: C5.1, C9.1, J1.13, U3.4 (EN), U3.5 (VIN)
CS1: IC1.1 (~CS), J1.1
CS2: IC2.1 (~CS), J1.2
DIN: IC1.8 (DIN), IC2.8 (DIN), J1.5
DOUT: IC1.9 (DOUT), IC2.9 (DOUT), J1.4
GND: C1.1, C2.2, C3.2, C5.2, C6.2, C7.2, C8.2, C9.2, C10.2, C11.2, C12.2, C13.2, C14.2, C15.2, C16.2, C17.2, C18.2, IC1.3 (GND), IC2.3 (GND), J1.14, R2.2, R3.2, R5.2, R6.2, R9.2, R10.2, R12.2, R13.2, R15.2, R16.2, R18.2, R19.2, R21.2, R22.2, R24.2, R25.2, U1.4 (GND), U2.2 (V-), U3.2 (GND), U4.2 (V-), U5.4 (V-), U6.4 (V-), U7.4 (V-), U8.4 (V-), U9.4 (V-), U10.4 (V-), U11.4 (V-), U12.4 (V-)
unnamed: R26.1, U5.1 (Rg)
unnamed: R26.2, U5.8 (Rg)
unnamed: R27.1, U6.1 (Rg)
unnamed: R27.2, U6.8 (Rg)
unnamed: R28.1, U7.1 (Rg)
unnamed: R28.2, U7.8 (Rg)
unnamed: R29.1, U8.1 (Rg)
unnamed: R29.2, U8.8 (Rg)
unnamed: R30.1, U9.1 (Rg)
unnamed: R30.2, U9.8 (Rg)
unnamed: R31.1, U10.1 (Rg)
unnamed: R31.2, U10.8 (Rg)
unnamed: R32.1, U11.1 (Rg)
unnamed: R32.2, U11.8 (Rg)
unnamed: R33.1, U12.1 (Rg)
unnamed: R33.2, U12.8 (Rg)
unnamed: R34.1, U5.6
unnamed: R35.1, U6.6
unnamed: R36.1, U7.6
unnamed: R37.1, U9.6
unnamed: R38.1, U11.6
unnamed: R39.1, U8.6
unnamed: R40.1, U10.6
unnamed: R41.1, U12.6
unnamed: C4.2, U3.1 (CB)
unnamed: C4.1, L2.1, U3.6 (SW)
SCLK: IC1.10 (SCLK), IC2.10 (SCLK), J1.3
SGA2: J2.2, U5.2 (-)
SGA3: J2.3, R3.1
SGAOUT: C3.1, IC1.7 (IN1), R34.2
SGAV+: R1.2, R2.1, U5.3 (+)
SGB2: J3.2, U6.2 (-)
SGB3: J3.3, R6.1
SGBOUT: C7.1, IC1.6 (IN2), R35.2
SGBV+: R4.2, R5.1, U6.3 (+)
SGC2: J4.2, U7.2 (-)
SGC3: J4.3, R10.1
SGCOUT: C8.1, IC1.5 (IN3), R36.2
SGCV+: R8.2, R9.1, U7.3 (+)
SGD2: J5.2, U8.2 (-)
SGD3: J5.3, R13.1
SGDOUT: C12.1, IC1.4 (IN4), R39.2
SGDV+: R11.2, R12.1, U8.3 (+)
SGE2: J6.2, U9.2 (-)
SGE3: J6.3, R16.1
SGEOUT: C10.1, IC2.7 (IN1), R37.2
SGEV+: R14.2, R15.1, U9.3 (+)
SGF2: J7.2, U10.2 (-)
SGF3: J7.3, R19.1
SGFOUT: C13.1, IC2.6 (IN2), R40.2
SGFV+: R17.2, R18.1, U10.3 (+)
SGG2: J8.2, U11.2 (-)
SGG3: J8.3, R22.1
SGGOUT: C11.1, IC2.5 (IN3), R38.2
SGGV+: R20.2, R21.1, U11.3 (+)
SGH2: J9.2, U12.2 (-)
SGH3: J9.3, R25.1
SGHOUT: C14.1, IC2.4 (IN4), R41.2
SGHV+: R23.2, R24.1, U12.3 (+)

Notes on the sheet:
(1A rated)
Wheatstone Bridging
Amplification
Connectors
ADC
2.5V Buffering
5V Reg
2.5V Reference

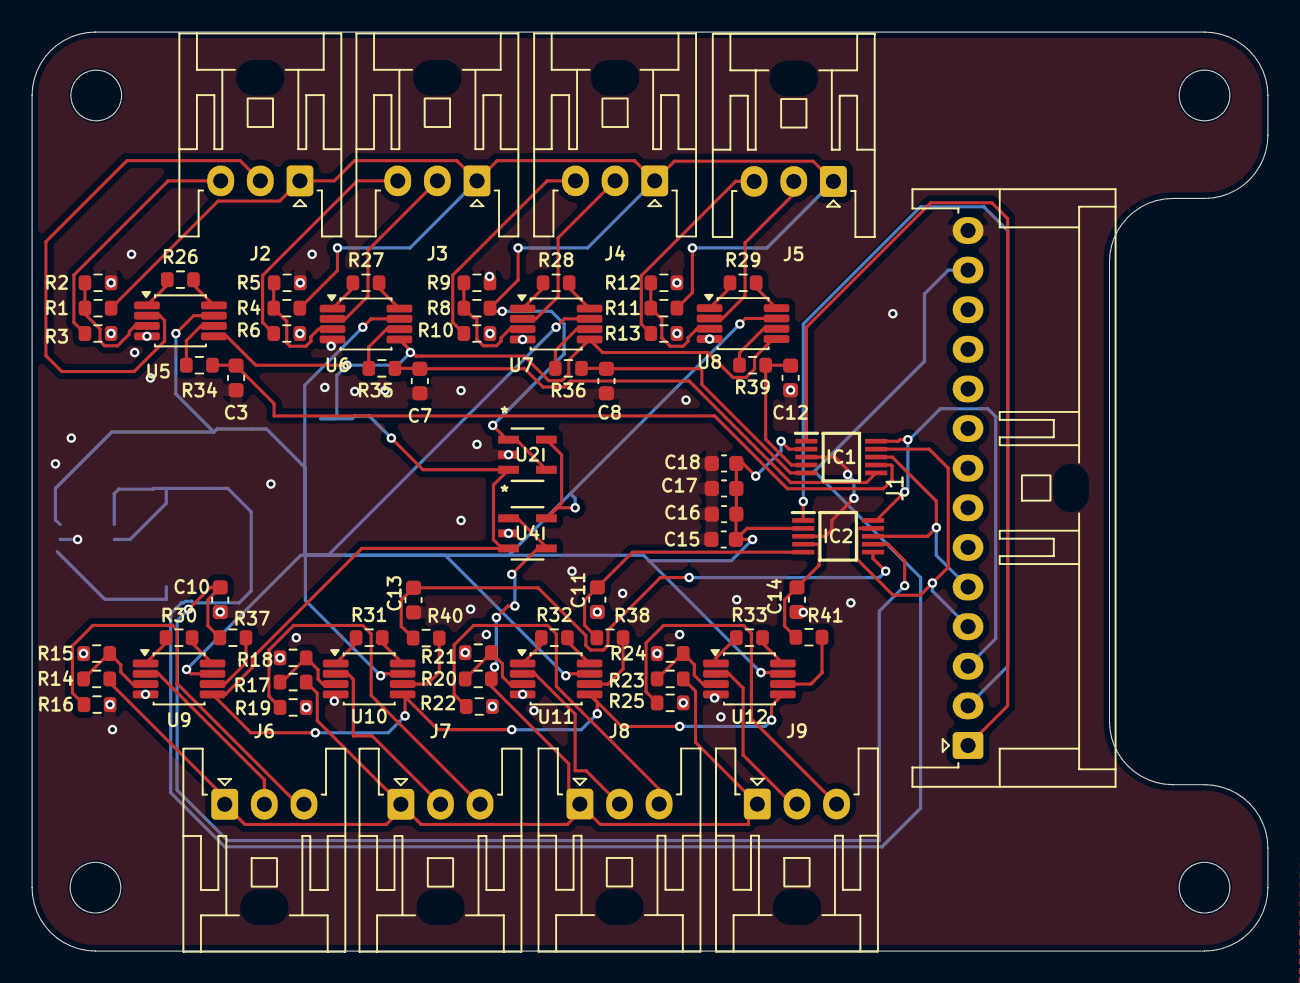
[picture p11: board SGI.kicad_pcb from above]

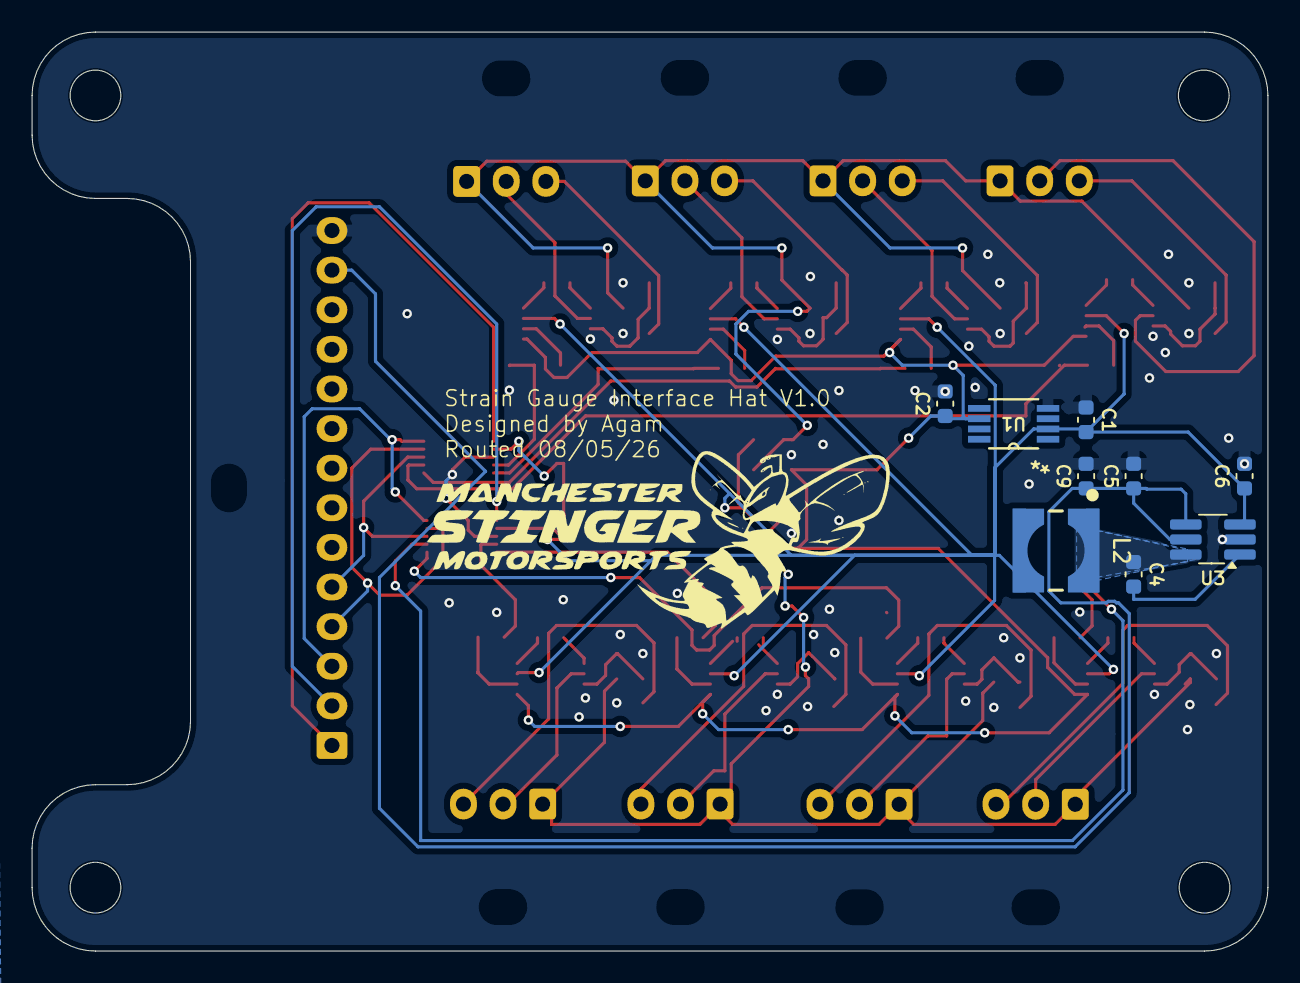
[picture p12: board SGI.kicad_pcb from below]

Board: 2 copper layers, 78.0 x 58.0 mm, 82 parts (9 on the bottom side), 69 nets.

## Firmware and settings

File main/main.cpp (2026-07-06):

#include "driver/gpio.h"
#include "config/BoardConfig.hpp"
#include "data/SensorQueues.hpp"
#include "esp_err.h"
#include "esp_log.h"
#include "freertos/FreeRTOS.h"
#include "freertos/task.h"
#include "tasks/ADC/ADC_task.hpp"
#include "tasks/CAN/CAN_task.hpp"
#include "tasks/GPS/GPS_task.hpp"
#include "tasks/IMU/IMU_task.hpp"

namespace
{
    const char *TAG = "JohnsonNode";

    struct TaskDefinition
    {
        TaskFunction_t function;
        const char *name;
        uint32_t stack_size;
        UBaseType_t priority;
    };

    bool create_task(const TaskDefinition& task)
    {
        const BaseType_t result = xTaskCreate(
            task.function,
            task.name,
            task.stack_size,
            nullptr,
            task.priority,
            nullptr);

        if (result != pdPASS)
        {
            ESP_LOGE(TAG, "Failed to create %s", task.name);
            return false;
        }

        ESP_LOGI(TAG, "Created %s", task.name);
        return true;
    }
}

extern "C" void app_main(void)
{
    ESP_ERROR_CHECK(SensorQueues::init());

    const TaskDefinition tasks[] = {
        {CAN_task, "CAN_task", 5'120, tskIDLE_PRIORITY + 3},
        {ADC_task, "ADC_task", 4'096, tskIDLE_PRIORITY + 2},
        {IMU_task, "IMU_task", 4'096, tskIDLE_PRIORITY + 2},
        {GPS_task, "GPS_task", 4'096, tskIDLE_PRIORITY + 2},
    };

    for (const TaskDefinition& task : tasks)
    {
        (void)create_task(task);
    }

    ESP_ERROR_CHECK(
        gpio_set_direction(BoardConfig::StatusLed::GPIO, GPIO_MODE_OUTPUT));

    bool led_is_on = false;
    while (true)
    {
        led_is_on = !led_is_on;
        ESP_ERROR_CHECK(
            gpio_set_level(BoardConfig::StatusLed::GPIO, led_is_on ? 1 : 0));
        vTaskDelay(
            pdMS_TO_TICKS(BoardConfig::StatusLed::BLINK_PERIOD_MS));
    }
}

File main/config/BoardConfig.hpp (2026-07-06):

#pragma once

#include <cstdint>

#include "driver/gpio.h"
#include "driver/i2c_master.h"
#include "driver/spi_master.h"
#include "driver/uart.h"

namespace BoardConfig
{
    namespace StatusLed
    {
        static constexpr gpio_num_t GPIO = GPIO_NUM_18;
        static constexpr uint32_t BLINK_PERIOD_MS = 500;
    }

    namespace ADC
    {
        static constexpr spi_host_device_t SPI_HOST = SPI2_HOST;
        static constexpr gpio_num_t MOSI_GPIO = GPIO_NUM_11;
        static constexpr gpio_num_t SCLK_GPIO = GPIO_NUM_12;
        static constexpr gpio_num_t MISO_GPIO = GPIO_NUM_13;
        static constexpr gpio_num_t CS_A_GPIO = GPIO_NUM_10;
        static constexpr gpio_num_t CS_B_GPIO = GPIO_NUM_9;

        // TI specifies ADC performance from 3.2 MHz to 8 MHz.
        static constexpr uint32_t SPI_CLOCK_HZ = 4'000'000;
        static constexpr uint32_t SAMPLE_RATE_HZ = 100;
        // The ADC full-scale reference is its 5 V VA supply.
        static constexpr float REFERENCE_VOLTAGE = 5.0f;
    }

    namespace IMU
    {
        static constexpr i2c_port_num_t I2C_PORT = I2C_NUM_0;
        static constexpr gpio_num_t SDA_GPIO = GPIO_NUM_16;
        static constexpr gpio_num_t SCL_GPIO = GPIO_NUM_15;

        static constexpr uint32_t I2C_CLOCK_HZ = 100'000;
        static constexpr uint32_t SAMPLE_RATE_HZ = 100;
        static constexpr uint32_t RETRY_PERIOD_MS = 2'000;
    }

    namespace GPS
    {
        static constexpr uart_port_t UART_PORT = UART_NUM_1;
        // ESP RX receives GPS TX; ESP TX drives GPS RX.
        static constexpr gpio_num_t RX_GPIO = GPIO_NUM_6;
        static constexpr gpio_num_t TX_GPIO = GPIO_NUM_5;
        static constexpr gpio_num_t PPS_GPIO = GPIO_NUM_17;

        static constexpr uint32_t BAUD_RATE = 9'600;
        static constexpr uint32_t READ_TIMEOUT_MS = 100;
    }

    namespace CAN
    {
        // ESP TX drives transceiver CAND; ESP RX receives transceiver CANR.
        static constexpr gpio_num_t RX_GPIO = GPIO_NUM_2;
        static constexpr gpio_num_t TX_GPIO = GPIO_NUM_1;
    }
}

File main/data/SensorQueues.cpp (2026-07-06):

#include "SensorQueues.hpp"

#include "freertos/FreeRTOS.h"
#include "freertos/queue.h"

namespace
{
    constexpr UBaseType_t ADC_QUEUE_LENGTH = 16;
    constexpr UBaseType_t IMU_QUEUE_LENGTH = 16;
    constexpr UBaseType_t GPS_QUEUE_LENGTH = 4;

    QueueHandle_t adc_queue = nullptr;
    QueueHandle_t imu_queue = nullptr;
    QueueHandle_t gps_queue = nullptr;

    template <typename Sample>
    void publish_to(QueueHandle_t queue, const Sample& sample)
    {
        if (queue != nullptr)
        {
            (void)xQueueSend(queue, &sample, 0);
        }
    }

    template <typename Sample>
    bool take_from(QueueHandle_t queue, Sample& sample)
    {
        return queue != nullptr && xQueueReceive(queue, &sample, 0) == pdTRUE;
    }
}

namespace SensorQueues
{
    esp_err_t init()
    {
        if (adc_queue != nullptr || imu_queue != nullptr || gps_queue != nullptr)
        {
            return ESP_ERR_INVALID_STATE;
        }

        adc_queue = xQueueCreate(ADC_QUEUE_LENGTH, sizeof(SensorData::ADCSample));
        imu_queue = xQueueCreate(IMU_QUEUE_LENGTH, sizeof(SensorData::IMUSample));
        gps_queue = xQueueCreate(GPS_QUEUE_LENGTH, sizeof(SensorData::GPSSample));

        if (adc_queue == nullptr || imu_queue == nullptr || gps_queue == nullptr)
        {
            if (adc_queue != nullptr)
            {
                vQueueDelete(adc_queue);
                adc_queue = nullptr;
            }
            if (imu_queue != nullptr)
            {
                vQueueDelete(imu_queue);
                imu_queue = nullptr;
            }
            if (gps_queue != nullptr)
            {
                vQueueDelete(gps_queue);
                gps_queue = nullptr;
            }
            return ESP_ERR_NO_MEM;
        }

        return ESP_OK;
    }

    void publish(const SensorData::ADCSample& sample)
    {
        publish_to(adc_queue, sample);
    }

    void publish(const SensorData::IMUSample& sample)
    {
        publish_to(imu_queue, sample);
    }

    void publish(const SensorData::GPSSample& sample)
    {
        publish_to(gps_queue, sample);
    }

    bool take(SensorData::ADCSample& sample)
    {
        return take_from(adc_queue, sample);
    }

    bool take(SensorData::IMUSample& sample)
    {
        return take_from(imu_queue, sample);
    }

    bool take(SensorData::GPSSample& sample)
    {
        return take_from(gps_queue, sample);
    }
}

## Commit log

2026-04-13 Add preliminary hardware
    [CAN_node_v2.kicad_pcb, CAN_node_v2.kicad_sch]
2026-04-13 Update kicad ver
    [CAN_node_v2.kicad_pcb, CAN_node_v2.kicad_sch]
2026-04-26 clean up and add hats
    [CAN_node_v2.kicad_pcb, CAN_node_v2.kicad_sch, Johnson-node.kicad_pcb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]
2026-05-08 update SGIH
    [SGI.kicad_pcb]
2026-05-12 finish schem
    [Johnson-node.kicad_sch]
2026-05-13 placement of components
    [Johnson-node.kicad_pcb, Johnson-node.kicad_sch]
2026-05-14 minor changes
    [IGL.kicad_pcb, IGL.kicad_sch, Johnson-node.kicad_pcb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]
2026-05-14 add onboard reg
    [IGL.kicad_pcb, IGL.kicad_sch, Johnson-node.kicad_pcb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]
2026-05-15 3d models
    [IGL.kicad_pcb, Johnson-node.kicad_pcb, Johnson-node.kicad_sch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]
2026-05-15 final ordered version
    [SGI.kicad_pcb, SGI.kicad_sch]
2026-06-17 strain gauge hell
    [.step, IGL.kicad_pcb, IGL.kicad_sch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]
2026-06-17 pull AINBs to 3V3
    [front.kicad_sch]
2026-06-17 change switching reg to adjustable
    [front.kicad_sch]
2026-06-17 add all footprints
    [front.kicad_pcb, front.kicad_sch]
2026-06-17 begin rear board
    [rear.kicad_pcb, rear.kicad_sch]
2026-06-17 6 wishbones
    [rear.kicad_sch]
2026-06-17 this is worse than torture
    [front.kicad_pcb, front.kicad_sch, rear.kicad_pcb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]
2026-06-17 I hate everything and everyone
    [HAT.kicad_pcb, HAT.kicad_sch, front.kicad_sch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]
2026-06-18 things are looking up
    [HAT.kicad_pcb, HAT.kicad_sch, TEENY_DUAL_LINEAR.kicad_pcb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]
2026-06-18 its finally over
    [HAT.kicad_pcb, HAT.kicad_sch, TEENY_ROSETTE.kicad_pcb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]
2026-06-20 accelerometer code example
    [HAT.kicad_pcb, TEENY_DUAL_LINEAR.kicad_pcb, TEENY_ROSETTE.kicad_pcb]
2026-07-06 ALL ZE CODEgit add .
    [Johnson-node.kicad_pcb]
2026-10-05 added 5v and 3v3 lines on 14 pin conn
2026-11-04 Changed PCB to 4 layer and added divider footprints.
2026-11-04 Improved placement and routing of switching regulators
